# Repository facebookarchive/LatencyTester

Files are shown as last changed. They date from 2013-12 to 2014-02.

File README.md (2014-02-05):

Latency Tester
==============

Latency Tester

Firmware, Schematics, and Mechanicals for the Oculus Latency Tester.

https://www.oculusvr.com/order/latency-tester/

Firmware
--------

The Latency Tester firmware uses the CooCox CoIDE for development along with 
the gcc-arm-embedded toolchain.

The ST-Link/V2 is the cheapest way to load firmware onto a Latency Tester
board, though any SWD compatible programmer should work.  You can follow these steps
to set up a build environment and load firmware onto the board:

1. Install ST-Link drivers if you haven't: http://www.st.com/web/en/catalog/tools/PF258167
2. Install CoCenter: http://www.coocox.org/CooCox_CoIDE.htm
3. Through CoCenter, install CooCox and CoFlash
4. Install gcc-arm-embedded: https://launchpad.net/gcc-arm-embedded/+download
5. Set up gcc-arm-embedded in CooCox: http://www.coocox.org/CoIDE/Compiler_Settings.html
6. Clone our LatencyTester repository to C:\CooCox\CoIDE\workspace
7. Open the LatencyTester.coproj
8. Build
9. Plug the ST-Link into the board's 10 pin SWD header.
10. Plug in USB to power the board.
12. Download code to Flash 
13. Enjoy!

Note that the USB Product ID is set to 0x0101, which matches the production
version of the Latency Tester.  If you modify the firmware in a way that
changes the USB interface, please change the Product ID to 0x0100.

Mechanical
----------

The Mechanical folder contains STLs of a version of the Latency Tester housing
that is printable on low cost 3D printers as well as STEP files of the original
injection molded housing.

Schematics
----------

The Schematics folder contains an image of the schematic, as well as Eagle CAD files
of the schematic and board layout.

You can also order PCBs directly from OSH Park:

* Main PCB: http://oshpark.com/shared_projects/SHWtp0zm
* Sensor PCB: http://oshpark.com/shared_projects/nyOrdIp9

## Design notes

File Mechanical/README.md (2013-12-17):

License
=======
This work is licensed under a Creative Commons Attribution 4.0 International License.

http://creativecommons.org/licenses/by/4.0/

Assembly
--------
Print one latencytester-top without supports and one latencytester-bottom with supports. Latencytester-top can be printed with support material, but the logo on the front may not look as nice.

Glue the (already assembled) sensor board into the bottom of the latency tester bottom. Hot melt glue works well for this. Rotation is not critical, though you may have to twist the cable connecting the two boards a little to get the mounting holes to line up.

Press the main PCB into the top of the latency tester and screw it all together with three M2x6 machine screws. M2x5 up to M2x10 will also do.

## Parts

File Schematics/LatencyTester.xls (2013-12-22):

Qty | Value | Device | Package | Parts | Description | Part Number | Source
8 | 80 | R-US_R0402 | R0402 | R1 R2 R3 R4 R5 R6 R7 R8 | 0402 80 Ohm 5% Resistor
6 | 1.5K | R-US_R0402 | R0402 | R9 R12 R13 R14 R15 R16 | 0402 1.5K Ohm 5% Resistor
2 | 22 | R-US_R0402 | R0402 | R10 R11 | 0402 22 Ohm 5% Resistor
2 | 4.7K | R-US_R0402 | R0402 | R17 R18 | 0402 4.7K Ohm 5% Resistor
1 | 0.01uF | C-EUC0402 | C0402 | C3 | 0402 0.01uF X7R 10% Ceramic Capacitor
8 | 0.1uF | C-EUC0402 | C0402 | C4 C5 C6 C7 C9 C10 C11 C12 | 0402 0.1uF X7R 10% Ceramic Capacitor
2 | 1.0uF | C-EUC0402 | C0402 | C1 C8 | 0402 1.0uF X5R 10% Ceramic Capacitor
2 | 10uF | C-EUC0805 | C0805 | C2 C13 | 0805 10uF X5R 10% Ceramic Capacitor
1 | MMZ1005S601C | INDUCTOR-L0402 | C402 | L1 | 0402 Chip Ferrite Bead | MMZ1005S601C | Digikey
1 | 8.00MHz | RESONATOR-PQRV-C | PQRV | Z1 |  | PRQV8.00CR5010Y000 | Digikey
4 | BC807 | TRANSISTOR_BJT_PNP-SOT-323 | SOT-323 | Q1 Q2 Q3 Q4 | BJT | BC807-25W-7 | Mouser
1 | CON-USB-F-MINI-B-VERT | CON-USB-F-MINI-B-VERT | 651005136421 | USB1 | USB Female connector | 651005136421 | Digikey
1 | GO | SW_TACT_4P-ADTS2 | ADTS2 | SW1 |  | ADTS24NV | Digikey
1 | SWD-GRPB5 | SWD-GRPB5 | GRPB5 | J1 | DNP
1 | TCS3414FN | TCS3414FN | TCS3414FN | U1 | TAOS Digital Color Sensor | TCS3414FN | Digikey
1 | STM32F102C6 | IC_UC_STM32 | LQFP48 | U2 | STM32F102C6 | STM32F102C6T6A | Digikey
1 | TPS73533DRV | TPS735XXDRV | SON-6 | U3 | Texas Instruments 500mA | TPS73533DRVT | Digikey
1 | LTC-4624JR | LTC-4624JR | LTC-4624 | U4 | LITE-ON triple digit seven-segment display. | LTC-4624JR | Digikey
1 | TLC5916D | TLC5916D | SOIC-16 | U5 | TI 8-channel constant-current led sink drivers. | TLC5916IDR | Digikey

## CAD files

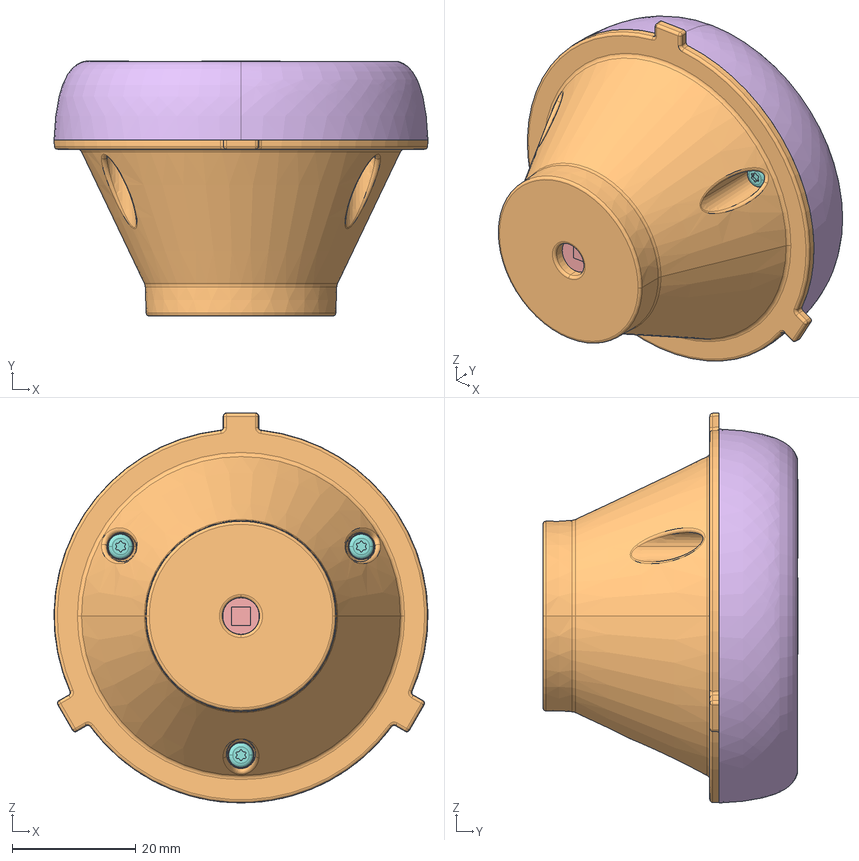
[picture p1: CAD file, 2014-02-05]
Mechanical/InjectionMoldingModels/Oculus latency tester assembly.stp
60.5 x 41.3 x 63.1 mm
OC00001
OCULUS_TOPPCB
OC00003
OCULUS_LOWERPCB
OC00002
OC00004
99397A192 x 3

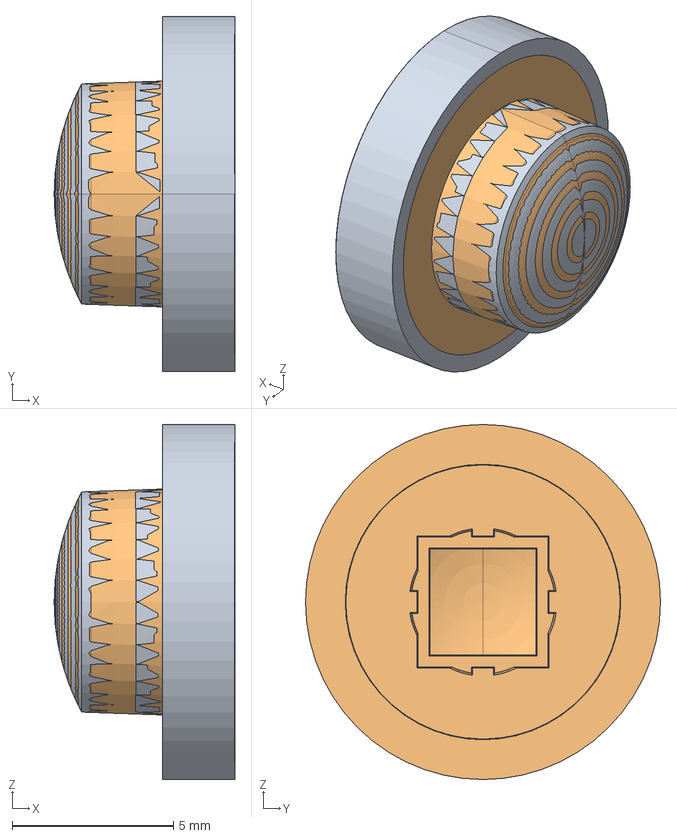
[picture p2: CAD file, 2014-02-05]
Mechanical/InjectionMoldingModels/Oculus latency tester button.stp
5.60 x 11.0 x 11.0 mm

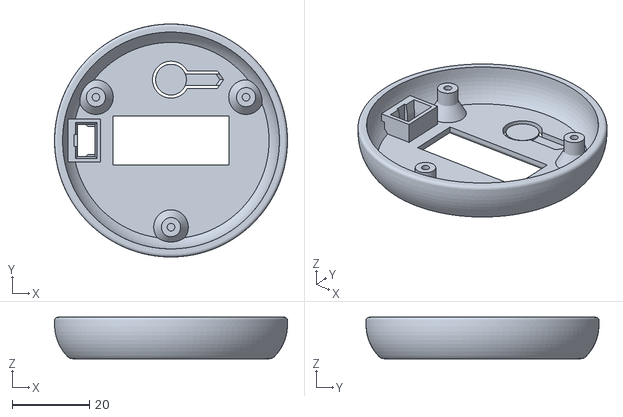
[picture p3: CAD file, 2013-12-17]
Mechanical/latencytester-top.stl
60.5 x 60.5 x 10.8

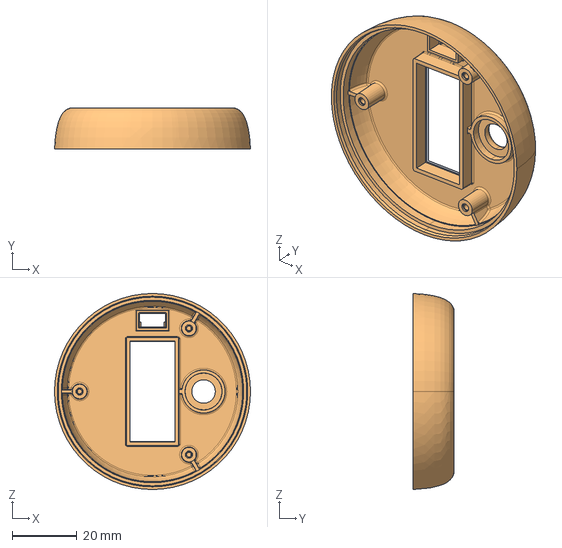
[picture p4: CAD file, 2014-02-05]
Mechanical/InjectionMoldingModels/Oculus latency tester upper housing.stp
60.5 x 12.8 x 60.5 mm

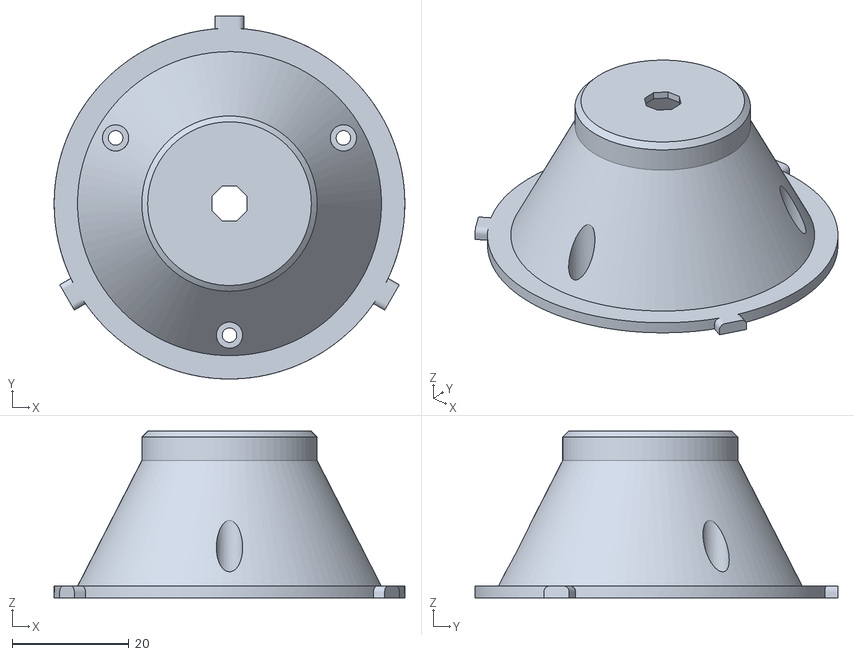
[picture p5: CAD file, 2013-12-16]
Mechanical/latencytester-bottom.stl
60.0 x 62.1 x 28.5

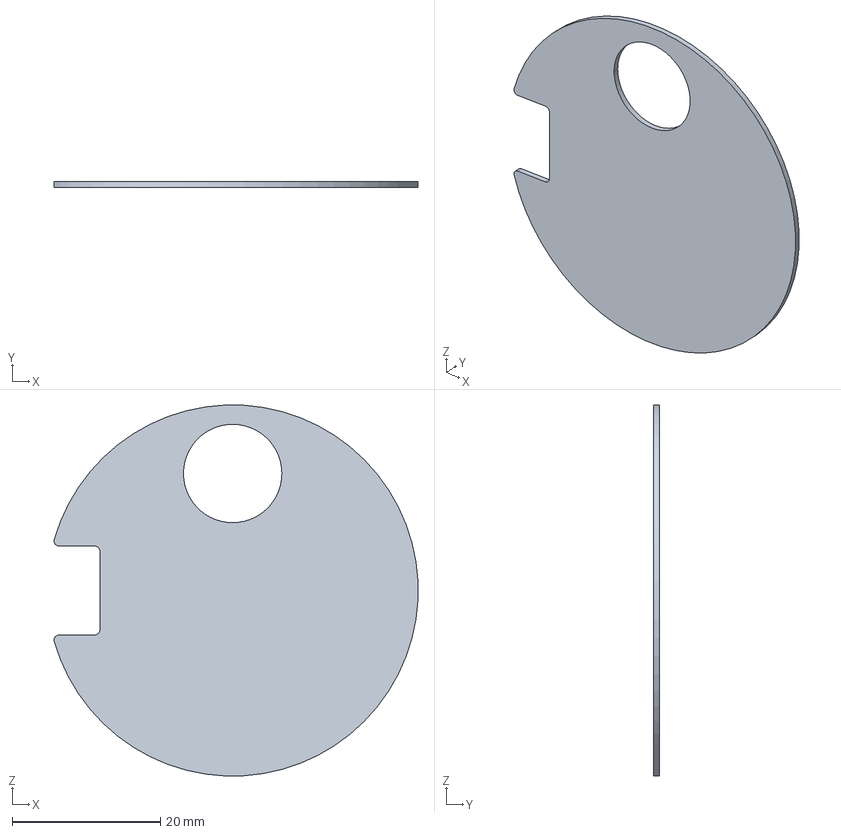
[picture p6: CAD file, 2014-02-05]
Mechanical/InjectionMoldingModels/Oculus latency tester label.stp
49.0 x 0.813 x 50.0 mm

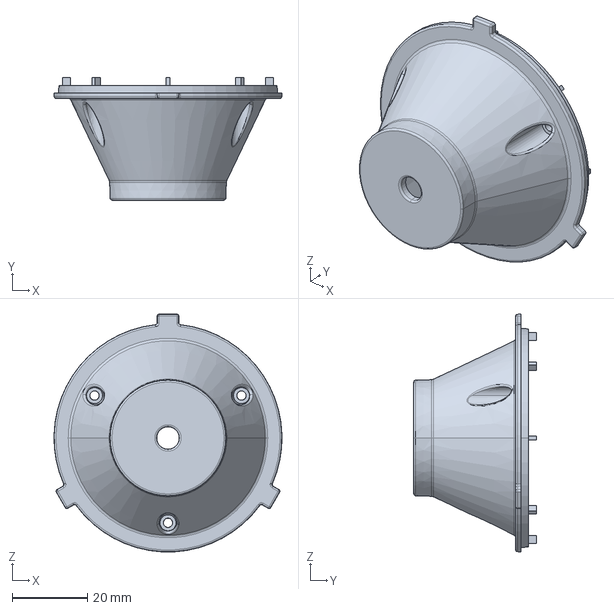
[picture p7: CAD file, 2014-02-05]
Mechanical/InjectionMoldingModels/Oculus latency tester lower housing.stp
60.5 x 32.5 x 63.1 mm

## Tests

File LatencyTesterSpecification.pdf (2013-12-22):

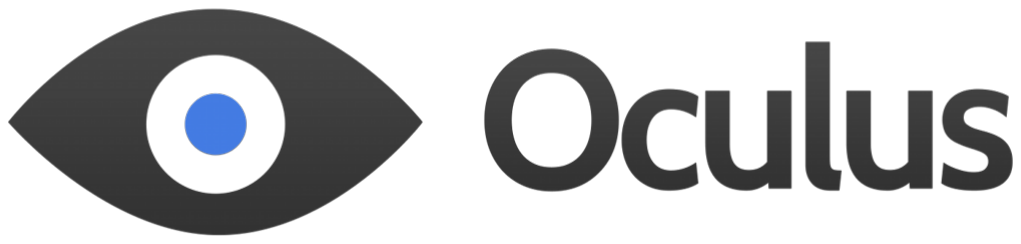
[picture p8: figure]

# Latency Tester Specification

### Nirav Patel

### Revision 0.4 3 March 2013

CONTENTS | CONTENTS

## Contents

1 Revision History | 3
2 Introduction | 4
3 Using the Latency Tester | 5
4 HID In Reports | 7
5 Feature Reports | 11
Latency Tester Specification | 2

1 REVISION HISTORY

## 1 Revision History

Revision | Date | Description
0.1 | 30-1-2013 | Preliminary specification.
0.2 | 7-2-2013 | Change button behavior, add bootloader.
0.3 | 23-2-2013 | Add usage instructions.
0.4 | 3-3-2013 | Rename reports and add Display report.
Latency Tester Specification | 3

2 INTRODUCTION

## 2 Introduction

Latency Tester is an HID class Full Speed USB device used to measure full system latency for the Oculus Rift. For more information about HID, see the Device Class Definition for Human Interface Devices¹
- Vendor ID: 0x2833
- Product ID: 0x0101
- Vendor String: Oculus VR, Inc.
- Product String: Latency Tester
- Serial String: Custom generated per device

1http://www.usb.org/developers/devclass_docs/HID1_11.pdf

Latency Tester Specification | 4

3 USING THE LATENCY TESTER

## 3 Using the Latency Tester

### 3.1 Timing the System

The simplest way to use the Latency Tester is to use it directly to time an event.

1. Flip the screen buffer from a color that is not the target color to the target color.
2. Send a StartTest report containing the target color.
3. Wait for the Latency Tester to return a ColorDetected packet, containing the time elapsed.

### 3.2 Emulating the Tracker

The usage of the Latency Tester can be tweaked slightly to more closely match the motion-to-photon behavior of the Tracker and Rift.

1. Make sure the screen is not at the target color.
2. Send a StartTest report containing the target color.
3. Wait for the Start packet from the Latency Tester.
4. Flip the screen buffer to the target color.
5. Wait for the Latency Tester to return a ColorDetected packet, containing the time elapsed.

### 3.3 Calibration

The Latency Tester comes calibrated for the Oculus Rift DK. It can also be re-calibrated to be used to test other displays. The calibration values are reset to the Oculus Rift DK values after resetting the device.

1. Set the screen to (0, 0, 0).
2. Send a Calibrate report with (0, 0, 0).
3. Set the screen to (255, 255, 255).
4. Send a Calibrate report with (255, 255, 255).
Latency Tester Specification | 5

3.4 Getting Sensor Samples | 3 USING THE LATENCY TESTER

### 3.4 Getting Sensor Samples

The Latency Tester can be configured to report a constant stream of color samples at 1000 Hz.

1. Send a Configuration report with the SendSamples bit set.
2. Read the Samples reports coming from the Tester.
Latency Tester Specification | 6

4 HID IN REPORTS

## 4 HID In Reports

The IN reports appear on Endpoint 1.

### 4.1 Samples

The 64 byte Sample report contains up to 20 RGB samples of light intensity data.

0 | 1 | 2 | 3 | 4 | 5 | 6 | 7 | 8 | 9 10 11 12 13 14 15 16 17 18 19 20 21 22 23 24 25 26 27 28 29 30 31
0 | ReportID = 1 | SampleCount | Timestamp
4 | Samples
❤❤❤❤❤❤❤❤❤❤❤❤❤❤❤❤❤❤❤❤❤❤❤❤❤❤❤❤❤❤❤❤❤❤❤ ❤❤❤❤

❤❤❤❤

❤❤❤❤

❤❤❤❤

❤❤❤❤

❤❤❤❤

❤❤❤❤

❤❤❤❤

❤❤❤

- ReportID (8 bits): The USB Report ID for this report is 1.
- SampleCount (8 bits): The number of RGB samples in the Samples field.
- Timestamp (16 bits): The timestamp of the first sample in the report. As the internal sampling rate is 1000 Hz, this unit is equivalent to milliseconds.
- Samples (60 bytes): Each sample is 3 bytes long and contains 8 bits each of red, green, and blue, which represents the luminosity values detected on the screen for each color at each sampling time.
Latency Tester Specification | 7

4.2 ColorDetected | 4 HID IN REPORTS

### 4.2 ColorDetected

The 13 byte ColorDetected report is fired when the Latency Tester detects that the screen has switched to within a threshold of the target value. The trigger is armed
by a StartTest feature report.
0 | 1 | 2 | 3 | 4 | 5 | 6 | 7 | 8 | 9 10 11 12 13 14 15 16 17 18 19 20 21 22 23 24 25 26 27 28 29 30 31
0 | ReportID = 2 | CommandID | Timestamp[0:7]
4 | Timestamp[8:15] | Elapsed | TriggerValue[0:7]
8 | TriggerValue[8:23] | TargetValue[0:15]
12 | TargetValue[16:23]
- ReportID (8 bits): The USB Report ID for this report is 2.
- CommandID (16 bits): An ID to identify related events, like a StartTest set, TestStarted report, and the resulting ColorDetected report.
- Timestamp (16 bits): The timestamp of the trigger fire. As the internal sampling rate is 1000 Hz, this unit is equivalent to milliseconds.
- Elapsed (16 bits): The time elapsed between the StartTest and the screen switching to within the threshold of the target value. The value is in milliseconds.
- TriggerValue (24 bits): The RGB sample that was within the threshold and triggered the firing of the report.
- TargetValue (24 bits): The RGB value that the display was set to.
Latency Tester Specification | 8

4.3 TestStarted | 4 HID IN REPORTS

### 4.3 TestStarted

The 8 byte TestStarted report is fired when a StartTest report is sent to it, indicating the start of the timer. A ColorDetected report will then be sent after the color change is detected.

0 | 1 | 2 | 3 | 4 | 5 | 6 | 7 | 8 | 9 10 11 12 13 14 15 16 17 18 19 20 21 22 23 24 25 26 27 28 29 30 31
0 | ReportID = 3 | CommandID | Timestamp[0:7]
4 | Timestamp[8:15] | TargetValue
- ReportID (8 bits): The USB Report ID for this report is 3.
- CommandID (16 bits): An ID to identify related events, like a StartTest report, TestStarted report, and the resulting ColorDetected report.
- Timestamp (16 bits): The timestamp of the test start. As the internal sampling rate is 1000 Hz, this unit is equivalent to milliseconds.
- TargetValue (24 bits): The RGB value that the display should be set to. This can be changed in the ButtonConfig feature report.
Latency Tester Specification | 9

4.4 Button | 4 HID IN REPORTS

### 4.4 Button

The 5 byte Button report is fired when the button on the Latency Tester is pressed.
It can be used by the application similarly to a keyboard button press to begin the StartTest, TestStarted, ColorDetected sequence.
0 | 1 | 2 | 3 | 4 | 5 | 6 | 7 | 8 | 9 10 11 12 13 14 15 16 17 18 19 20 21 22 23 24 25 26 27 28 29 30 31
0 | ReportID = 4 | CommandID | Timestamp[0:7]
4 | Timestamp[8:15]
- ReportID (8 bits): The USB Report ID for this report is 4.
- CommandID (16 bits): An ID to identify related events, like a StartTest, Test-Started report, and the resulting ColorDetected report.
- Timestamp (16 bits): The timestamp of the button press. As the internal sampling rate is 1000 Hz, this unit is equivalent to milliseconds.
Latency Tester Specification | 10

5 FEATURE REPORTS

## 5 Feature Reports

Feature Reports are read from and written to Endpoint 0, which is the Control Endpoint.

### 5.1 Configuration

The 5 byte Configuration report has a ReportID of 5. It contains a bitfield used to query or alter the operation of the Latency Tester.

0 | 1 | 2 | 3 | 4 | 5 | 6 | 7 | 8 | 9 10 11 12 13 14 15 16 17 18 19 20 21 22 23 24 25 26 27 28 29 30 31
0 | ReportID = 5 | a | Threshold[0:15]
4 | Threshold[16:23]
- ReportID (8 bits): The USB Report ID for this report is 5.
- (a) SendSamples (1 bit): Enables the Samples report. The default value is 0.
- Threshold (24 bits): The threshold for triggering a detected display change. For example, with a TargetValue of (255, 255, 255) a threshold set to (50, 50,
50) would result in a trigger at the first sample (205, 205, 205) or higher.
Latency Tester Specification | 11

5.2 Bootload | 5 FEATURE REPORTS

### 5.2 Bootload

The 4 byte Bootload report has a ReportID of 6. Setting the payload to non-zero reboots the device into a bootloading mode where new firmware can be loaded onto the Latency Tester over USB.

0 | 1 | 2 | 3 | 4 | 5 | 6 | 7 | 8 | 9 10 11 12 13 14 15 16 17 18 19 20 21 22 23 24 25 26 27 28 29 30 31
0 | ReportID = 6 | CommandID | Bootload
- ReportID (8 bits): The USB Report ID for this report is 6.
- CommandID (16 bits): Unused.
- Bootload (8 bits): Setting this to a non-zero value reboots the device into bootloader mode immediately.
Latency Tester Specification | 12

5.3 Calibrate | 5 FEATURE REPORTS

### 5.3 Calibrate

The 4 byte Calibrate report has a ReportID of 7. It is used to calibrate the color sensor in the Latency Tester to the display being tested. Set the display to a color, wait for the display to be completely switched, and then set the Calibrate report with that color. This should be repeated on any new display for the colors (255, 255, 255) and
(0, 0, 0).
0 | 1 | 2 | 3 | 4 | 5 | 6 | 7 | 8 | 9 10 11 12 13 14 15 16 17 18 19 20 21 22 23 24 25 26 27 28 29 30 31
0 | ReportID = 7 | Value
- ReportID (8 bits): The USB Report ID for this report is 7.
- Value (24 bit): The RGB value being calibrated to.
Latency Tester Specification | 13

5.4 StartTest | 5 FEATURE REPORTS

### 5.4 StartTest

The 6 byte StartTest report tells the Latency Tester to setup the change to the color specified in the report. The TestStarted report is sent back with the specified color when the timer starts.

0 | 1 | 2 | 3 | 4 | 5 | 6 | 7 | 8 | 9 10 11 12 13 14 15 16 17 18 19 20 21 22 23 24 25 26 27 28 29 30 31
0 | ReportID = 8 | CommandID | TargetValue[0:7]
4 | TargetValue[8:23]
- ReportID (8 bits): The USB Report ID for this report is 8.
- CommandID (16 bits): An ID to identify related events, like a StartTest, Test-Started report, and the resulting ColorDetected report.
- TargetValue (24 bits): The RGB value that the display is being set to.
Latency Tester Specification | 14

5.5 Display | 5 FEATURE REPORTS

### 5.5 Display

The 6 byte Display report configures and allows the setting of data on the 3.5 digit 7-segment display on the Latency Tester.

0 | 1 | 2 | 3 | 4 | 5 | 6 | 7 | 8 | 9 10 11 12 13 14 15 16 17 18 19 20 21 22 23 24 25 26 27 28 29 30 31
0 | ReportID = 9 | Mode | Value[0:15]
4 | Value[16:23]
- ReportID (8 bits): The USB Report ID for this report is 9.
- Mode (8 bits):
– 0: The default mode, where the Latency Tester automatically sets the value on the display when tests are run and completed. The Value field is ignored with this mode.
– 1: The display is set to the 32-bit unsigned integer in the Value field in milliseconds.
– 2: Raw access to the segments on the display using Value as a set of bitmasks. Byte 0 is Digit 1, byte 1 is the Colon digit, byte 2 is Digit 2, and byte 3 is Digit 3. See the LTC-4624 datasheet²
for bit to segment
mapping.
- Value (32 bits): The field depends on the Mode.

2http://optoelectronics.liteon.com/en-us/api/DwonloadFileHandler.ashx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 (http://optoelectronics.liteon.com/en-us/api/DwonloadFileHandler.ashx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)

Latency Tester Specification | 15

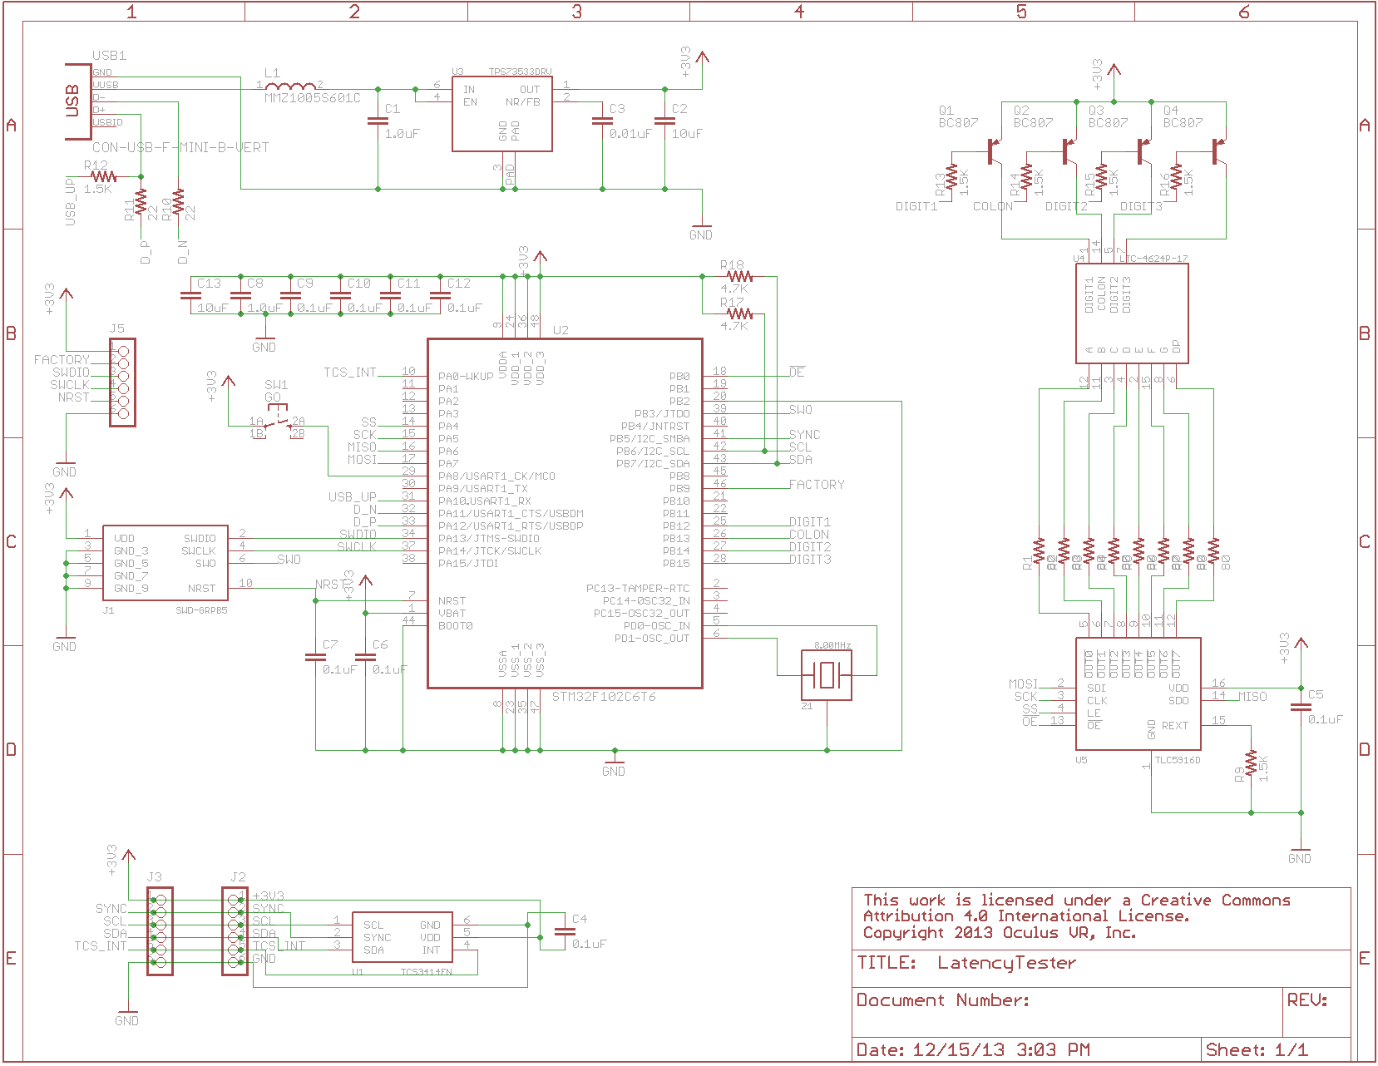
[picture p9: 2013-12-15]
Schematics/LatencyTester.png

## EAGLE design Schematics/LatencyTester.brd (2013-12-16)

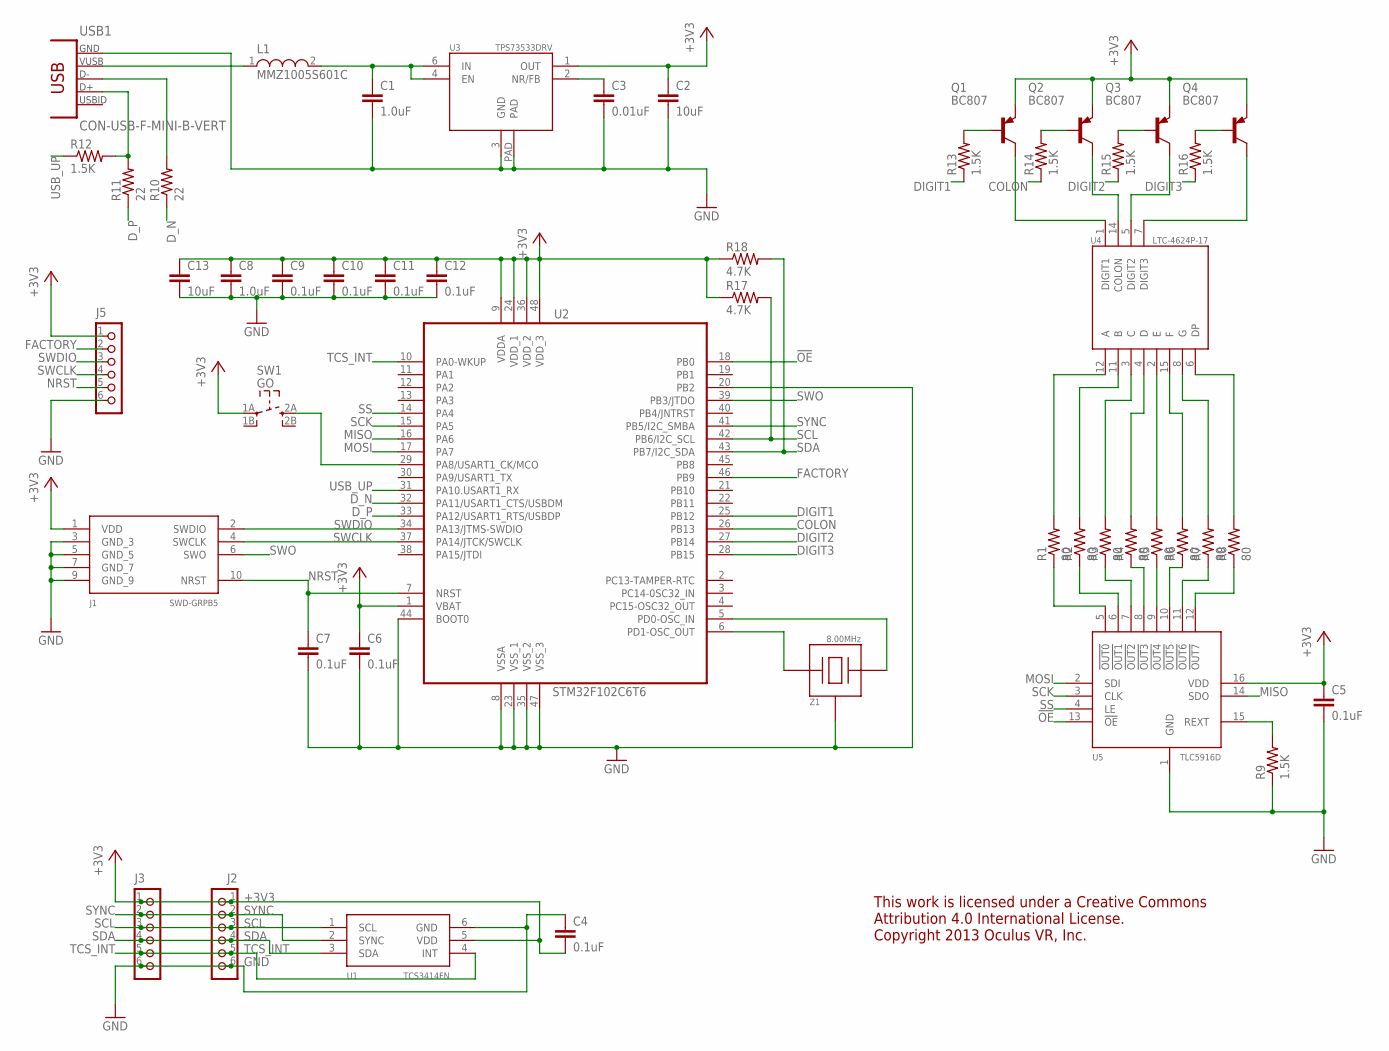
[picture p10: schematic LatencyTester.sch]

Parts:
C1, C8: 1.0uF; C0402
C2, C13: 10uF; C0805
C3: 0.01uF; C0402
C4, C5, C6, C7, C9, C10, C11, C12: 0.1uF; C0402
J1: SWD-GRPB5; GRPB5
J2, J3, J5: CON_HEADER_1X06-PTH; M1X6
L1: MMZ1005S601C; C402
Q1, Q2, Q3, Q4: BC807; SOT-323
R1, R2, R3, R4, R5, R6, R7, R8: 80; R0402
R9, R12, R13, R14, R15, R16: 1.5K; R0402
R10, R11: 22; R0402
R17, R18: 4.7K; R0402
SW1: GO; ADTS2
U1: TCS3414FN
U2: STM32F102C6T6; LQFP48
U3: TPS73533DRV; SON-6
U4: LTC-4624P-17; LTC-4624
U5: TLC5916D; SOIC-16
USB1: CON-USB-F-MINI-B-VERT; 651005136421
Z1: 8.00MHz; PQRV

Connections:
!OE: U2.18 (PB0), U5.13 (!OE)
+3V3: C2.1, C4.2, C5.1, C6.1, C8.1, C9.1, C10.1, C11.1, C12.1, C13.1, J1.1 (VDD), J2.1, J3.1, J5.1, Q1.2 (E), Q2.2 (E), Q3.2 (E), Q4.2 (E), R17.1, R18.1, SW1.1A (1), U1.5 (VDD), U2.1 (VBAT), U2.9 (VDDA), U2.24 (VDD_1), U2.36 (VDD_2), U2.48 (VDD_3), U3.1 (OUT), U5.16 (VDD)
COLON: R14.1, U2.26 (PB13)
D1_N: R10.2, USB1.2 (D-)
D1_P: R11.2, R12.2, USB1.3 (D+)
DIGIT1: R13.1, U2.25 (PB12)
DIGIT2: R15.1, U2.27 (PB14)
DIGIT3: R16.1, U2.28 (PB15)
D_N: R10.1, U2.32 (PA11/USART1_CTS/USBDM)
D_P: R11.1, U2.33 (PA12/USART1_RTS/USBDP)
FACTORY: J5.2, U2.46 (PB9)
GND: C1.2, C2.2, C3.2, C4.1, C5.2, C6.2, C7.2, C8.2, C9.2, C10.2, C11.2, C12.2, C13.2, J1.3 (GND_3), J1.5 (GND_5), J1.7 (GND_7), J1.9 (GND_9), J2.6, J3.6, J5.6, R9.1, U1.6 (GND), U2.8 (VSSA), U2.20 (PB2), U2.23 (VSS_1), U2.35 (VSS_2), U2.44 (BOOT0), U2.47 (VSS_3), U3.3 (GND), U3.PAD, U5.1 (GND), USB1.5 (GND), Z1.2 (GND)
MISO: U2.16 (PA6), U5.14 (SDO)
MOSI: U2.17 (PA7), U5.2 (SDI)
unnamed: R1.1, U5.5 (!OUT0)
unnamed: R2.1, U5.6 (!OUT1)
unnamed: R3.1, U5.7 (!OUT2)
unnamed: R4.1, U5.8 (!OUT3)
unnamed: R5.1, U5.9 (!OUT4)
unnamed: R6.1, U5.10 (!OUT5)
unnamed: R7.1, U5.11 (!OUT6)
unnamed: R8.1, U5.12 (!OUT7)
unnamed: R1.2, U4.12 (A)
unnamed: R2.2, U4.11 (B)
unnamed: R3.2, U4.3 (C)
unnamed: R4.2, U4.4 (D)
unnamed: R5.2, U4.2 (E)
unnamed: R6.2, U4.15 (F)
unnamed: R7.2, U4.8 (G)
unnamed: R8.2, U4.6 (DP)
unnamed: U2.6 (PD1-OSC_OUT), Z1.1 (IN)
unnamed: U2.5 (PD0-OSC_IN), Z1.3 (OUT)
unnamed: Q1.3 (C), U4.1 (DIGIT1)
unnamed: Q2.3 (C), U4.14 (COLON)
unnamed: Q3.3 (C), U4.5 (DIGIT2)
unnamed: Q4.3 (C), U4.7 (DIGIT3)
unnamed: SW1.2A (3), U2.29 (PA8/USART1_CK/MCO)
unnamed: C3.1, U3.2 (NR/FB)
unnamed: R9.2, U5.15 (REXT)
unnamed: Q1.1 (B), R13.2
unnamed: Q2.1 (B), R14.2
unnamed: Q3.1 (B), R15.2
unnamed: Q4.1 (B), R16.2
NRST: C7.1, J1.10 (NRST), J5.5, U2.7 (NRST)
SCK: U2.15 (PA5), U5.3 (CLK)
SCL: J2.3, J3.3, R17.2, U1.1 (SCL), U2.42 (PB6/I2C_SCL)
SDA: J2.4, J3.4, R18.2, U1.3 (SDA), U2.43 (PB7/I2C_SDA)
SS: U2.14 (PA4), U5.4 (LE)
SWCLK: J1.4 (SWCLK), J5.4, U2.37 (PA14/JTCK/SWCLK)
SWDIO: J1.2 (SWDIO), J5.3, U2.34 (PA13/JTMS-SWDIO)
SWO: J1.6 (SWO), U2.39 (PB3/JTDO)
SYNC: J2.2, J3.2, U1.2 (SYNC), U2.41 (PB5/I2C_SMBA)
TCS_INT: J2.5, J3.5, U1.4 (INT), U2.10 (PA0-WKUP)
USB_UP: R12.1, U2.31 (PA10.USART1_RX)
VUSB: L1.1, USB1.1 (VUSB)
VUSB_FILTERED: C1.1, L1.2, U3.4 (EN), U3.6 (IN)

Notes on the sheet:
This work is licensed under a Creative Commons Attribution 4.0 International License. Copyright 2013 Oculus VR, Inc.

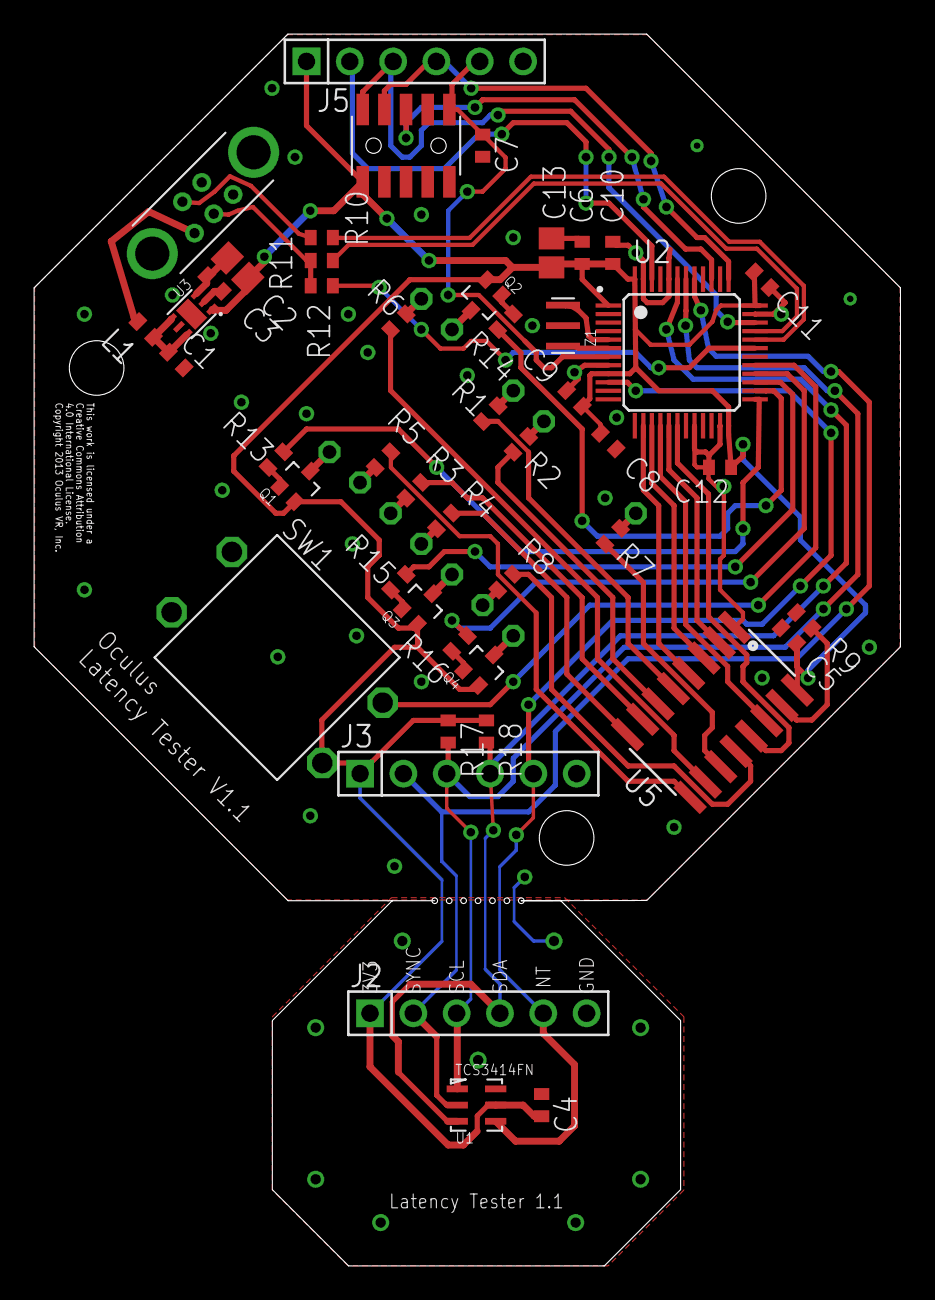
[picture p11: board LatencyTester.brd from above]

Board: 2 copper layers, 50.8 x 72.2 mm, 51 parts (0 on the bottom side), 56 nets.

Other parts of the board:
U$1, U$2, U$3: HOLE_3.2

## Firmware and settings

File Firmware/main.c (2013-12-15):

/*****************************************************************************

Filename    :   main.c
Content     :   Initialization and main loop for the Latency Tester
Created     :
Authors     :   Nirav Patel
Copyright   :   Copyright 2013 Oculus VR, Inc. All Rights reserved.

Licensed under the Apache License, Version 2.0 (the "License");
you may not use this file except in compliance with the License.
You may obtain a copy of the License at

http://www.apache.org/licenses/LICENSE-2.0

Unless required by applicable law or agreed to in writing, software
distributed under the License is distributed on an "AS IS" BASIS,
WITHOUT WARRANTIES OR CONDITIONS OF ANY KIND, either express or implied.
See the License for the specific language governing permissions and
limitations under the License.

*****************************************************************************/

#include "hw_config.h"
#include "usb_lib.h"
#include "usb_conf.h"
#include "usb_prop.h"
#include "usb_pwr.h"
#include "tick.h"
#include "sample_packet.h"
#include "feature_reports.h"
#include "trigger_packet.h"
#include "calibrate.h"
#include "tcs3414.h"
#include "segment.h"
#include <stdbool.h>
#include <stdlib.h>
#include <string.h>

static volatile bool ep1_ready = 1;

static feature_config_s config = {0};
static feature_dfu_s dfu = {0};
static feature_calibrate_s calibrate = {{0}};
static feature_trigger_s trigger = {0};
static feature_display_s display = {0};
static float sample_avg[3] = {0.0f};

uint8_t g_startup_failed;

#define DEBOUNCE (100)
#define TIMEOUT_OPTION (500)
#define AVG_ALPHA (0.4f)

#ifdef USE_TRACKER_V1
#define NUM_COLORS 2
#else
#define NUM_COLORS 3
#endif /* USE_TRACKER_V1 */

enum {
    MODE_IDLE,
    MODE_TRIGGER
};

enum {
    FACTORY_NONE,
    FACTORY_FULL,
    FACTORY_EMPTY,
    FACTORY_RED,
    FACTORY_GREEN,
    FACTORY_BLUE,
    FACTORY_DONE
};

static bool check_button_pressed(uint16_t timestamp)
{
    static bool button_value = 0;
    static uint16_t last_press = 0;

    bool ret = 0;
    bool new_value = GPIO_ReadInputDataBit(BUTTON_PORT, BUTTON_PIN);
    if (new_value && !button_value && ((uint16_t)(timestamp - last_press) > DEBOUNCE)) {
        ret = 1;
        last_press = timestamp;
    }

    button_value = new_value;
    return ret;
}

static void update_average(uint16_t *sample)
{
    for (uint8_t i = 0; i < NUM_COLORS; i++)
        sample_avg[i] = (sample[i]*AVG_ALPHA) + (sample_avg[i]*(1.0f-AVG_ALPHA));
}

static bool update_sample(uint16_t timestamp, uint8_t *sample, uint8_t *target, uint8_t *threshold)
{
    if (config.send_samples)
        sample_packet_update(timestamp, sample);

    // return 0 if any of the values are outside the threshold
    for (uint8_t i = 0; i < NUM_COLORS; i++) {
        if (abs(sample[i] - target[i]) > threshold[i]) {
            return 0;
        }
    }

    return 1;
}

static void update_factory(uint8_t factory_mode, uint8_t *sample)
{
    static const uint8_t full[] = {0xFF, 0xFF, 0xFF, 0xFF};
    static const uint8_t empty[] = {0, 0, 0, 0};

    switch (factory_mode) {
        case FACTORY_FULL:
            // Start by lighting all of the segments
            segment_set_raw(full);
            break;

        case FACTORY_EMPTY:
            // Then blank the display
            segment_set_raw(empty);
            break;

        case FACTORY_RED:
        case FACTORY_GREEN:
        case FACTORY_BLUE:
            // Then make sure each color in the sensor works
            segment_set_value(sample[factory_mode-FACTORY_RED]);
            break;
    }
}

int main(void)
{
    if (RCC_GetFlagStatus(RCC_FLAG_HSERDY) == RESET)
        g_startup_failed = 1;

    // Shut off JTAG and keep SWD on, needs to happen right after reset
    Configure_Debug();
    tick_init();

    // Initialize pins and interrupts
    Set_System();

    // Configure the USB hardware
    USB_Interrupts_Config();
    Set_USBClock();
    USB_Init();

#ifndef USE_AVAGO
    tcs_init();
#ifdef USE_7_SEG
    segment_init();
    if (g_startup_failed)
        segment_set_error();
    else
        segment_set_hello();
#endif /* USE_7_SEG */
#endif /* USE_AVAGO */

    uint32_t timestamp = tick_get();

    uint8_t sample[3] = {0};
    uint16_t raw[3] = {0};
    uint8_t sample_target[3] = {0};
    bool button_pressed = 0;
    bool got_trigger = 0;
    bool triggered = 0;
    bool got_report = 0;
    uint8_t mode = MODE_IDLE;
    uint8_t button_index = 0;
    uint32_t start_timestamp = 0;
    uint16_t command_id = 0;
    uint32_t trigger_timestamp = 0;
    uint32_t temp_timestamp = timestamp;

    // set the default values
    // TODO: for now, set the threshold to 128, 128, 255 since blue isn't connected
    config.threshold[0] = 128;
    config.threshold[1] = 128;
    config.threshold[2] = 255;

    feature_config_set(&config);

    // Check if we are in the programming/test jig
    uint8_t factory_mode = GPIO_ReadInputDataBit(FACTORY_PORT, FACTORY_PIN);

    while (1) {
        // Spin waiting for an event to happen
        do {
            temp_timestamp = tick_get();
            button_pressed |= check_button_pressed(temp_timestamp);
            got_report = feature_got_report();
        } while ((timestamp == temp_timestamp) &&
                 !button_pressed &&
                 !got_report);

        // Update feature reports if we got one
        if (got_report) {
            got_report = 0;
        }

        feature_config_get(&config);

        if (feature_calibrate_get(&calibrate)) {
            calibrate_update(sample_avg, calibrate.calibrate);
        }

        if (feature_dfu_get(&dfu)) {
            // TODO: Add HID bootloader support back to the Open Source release

            // Restart the device if we are told to
            if (dfu.use_dfu)
                Reset_Device();
        }

        if (feature_trigger_get(&trigger)) {
            got_trigger = 1;
            trigger_timestamp = timestamp;
        }

        if (feature_display_get(&display)) {
#ifdef USE_7_SEG
        	uint32_t value;

            // Update the display if we are in a mode where the PC sets it
            switch (display.mode) {
                case SEGMENT_MANUAL:
                	// Use memcpy to be safe about memory alignment
                	memcpy(&value, display.value, sizeof(uint32_t));
                    segment_set_value(value);
                    break;

                case SEGMENT_RAW:
                    segment_set_raw(display.value);
                    break;
            }
#endif /* USE_7_SEG */
        }

        // update the sample at every timestamp tick
        if (timestamp != temp_timestamp) {
            timestamp = temp_timestamp;
            // check if the color changed to the trigger value
#ifdef USE_AVAGO
            // TODO: connect blue
            raw[0] = ADC_GetConversionValue(ADC1);
            raw[1] = ADC_GetConversionValue(ADC2);
#else /* USE_AVAGO */
            tcs_end_measurement();
            tcs_start_measurement();
            tcs_read(raw);
#ifdef USE_7_SEG
            // only update the display if we are in auto mode and changes are happening
            if ((mode != MODE_IDLE) && (display.mode == SEGMENT_AUTO))
                segment_set_value(timestamp - start_timestamp);
            segment_update();
#endif /* USE_7_SEG */
#endif /* USE_AVAGO */

            update_average(raw);
            calibrate_apply(raw, sample);

            if (update_sample(timestamp, sample, sample_target, config.threshold) &&
                (mode != MODE_IDLE)) {
                triggered = 1;
            }
        }

        // Factory testing has several stages
        if (factory_mode) {
            if (button_pressed) {
                button_pressed = 0;
                factory_mode++;

                // Go into normal operation once testing is done
                if (factory_mode == FACTORY_DONE) {
                    factory_mode = FACTORY_NONE;
                    if (g_startup_failed)
                        segment_set_error();
                    else
                        segment_set_hello();
                }
            }

            update_factory(factory_mode, sample);

            continue;
        }

        if (triggered) {
            mode = MODE_IDLE;
            triggered = 0;
            // send the elapsed time if the trigger occurred
            uint32_t elapsed = timestamp - start_timestamp;
            trigger_packet(command_id, timestamp, elapsed > UINT16_MAX ? UINT16_MAX : elapsed, sample, sample_target);
            ep1_ready = 0;
        } else if (((mode == MODE_IDLE) || (timestamp - start_timestamp > TIMEOUT_OPTION)) && got_trigger) {
            // Only start the trigger if we aren't currently waiting for one
            mode = MODE_TRIGGER;
            got_trigger = 0;
            start_timestamp = trigger_timestamp;
            command_id = trigger.command_id;
            memcpy(sample_target, trigger.target, 3);
            trigger_start_packet(command_id, timestamp, sample_target);
            ep1_ready = 0;
        } else if (ep1_ready && button_pressed) {
            // increment the count used for the button each time
            button_index++;
            trigger_button_packet(button_index, timestamp);
            if ((display.mode == SEGMENT_AUTO))
                segment_set_waiting();
            button_pressed = 0;
            ep1_ready = 0;
        } else if (ep1_ready && config.send_samples) {
            // the normal sample packet has the lowest priority
            sample_packet_generate();
            sample_packet_send();
            ep1_ready = 0;
        }
    }
}

void EP1_IN_Callback(void)
{
    ep1_ready = 1;
}

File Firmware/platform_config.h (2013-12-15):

/*****************************************************************************

Filename    :   platform_config.h
Content     :   Pin definitions for the Latency Tester
Created     :
Authors     :   Nirav Patel
Copyright   :   Copyright 2013 Oculus VR, Inc. All Rights reserved.

Licensed under the Apache License, Version 2.0 (the "License");
you may not use this file except in compliance with the License.
You may obtain a copy of the License at

http://www.apache.org/licenses/LICENSE-2.0

Unless required by applicable law or agreed to in writing, software
distributed under the License is distributed on an "AS IS" BASIS,
WITHOUT WARRANTIES OR CONDITIONS OF ANY KIND, either express or implied.
See the License for the specific language governing permissions and
limitations under the License.

*****************************************************************************/

#ifndef _PLATFORM_CONFIG_H_
#define _PLATFORM_CONFIG_H_

#if defined(STM32L1XX_MD) || defined(STM32L1XX_HD)|| defined(STM32L1XX_MD_PLUS)
  #include "stm32l1xx.h"
#elif defined (STM32F10X_LD) || defined (STM32F10X_MD) || defined (STM32F10X_HD) || defined (STM32F10X_XL) || defined (STM32F10X_CL)
  #include "stm32f10x.h"
#endif

/* Define the STM32F10x hardware depending on the used evaluation board */
#if defined (USE_TRACKER_V1)

  #define USB_DISCONNECT                      GPIOA
  #define USB_DISCONNECT_PIN                  GPIO_Pin_2
  #define RCC_APB2Periph_GPIO_DISCONNECT      RCC_APB2Periph_GPIOA

#ifdef USE_AVAGO
  #define RED_PORT                            GPIOB
  #define RED_PIN                             GPIO_Pin_0
  #define RED_RCC                             RCC_APB2Periph_GPIOB
  #define RED_CHANNEL                         ADC_Channel_8
  #define GREEN_PORT                          GPIOB
  #define GREEN_PIN                           GPIO_Pin_1
  #define GREEN_RCC                           RCC_APB2Periph_GPIOB
  #define GREEN_CHANNEL                       ADC_Channel_9
  #define BLUE_PORT                           GPIOA
  #define BLUE_PIN                            GPIO_Pin_3
  #define BLUE_RCC                            RCC_APB2Periph_GPIOA
  #define BLUE_CHANNEL                        ADC_Channel_3
  #define BUTTON_PORT                         GPIOB
  #define BUTTON_PIN                          GPIO_Pin_10
  #define BUTTON_RCC                          RCC_APB2Periph_GPIOB
#else
  #define TCS_I2C                             I2C2
  #define TCS_I2C_RCC                         RCC_APB1Periph_I2C2
  #define TCS_SCL_PIN                         GPIO_Pin_10
  #define TCS_SDA_PIN                         GPIO_Pin_11
  #define TCS_SCL_SDA_PORT                    GPIOB
  #define TCS_SCL_SDA_RCC                     RCC_APB2Periph_GPIOB
  #define TCS_SYNC_PIN                        GPIO_Pin_5
  #define TCS_SYNC_PORT                       GPIOB
  #define TCS_SYNC_RCC                        RCC_APB2Periph_GPIOB
  #define BUTTON_PORT                         GPIOB
  #define BUTTON_PIN                          GPIO_Pin_0
  #define BUTTON_RCC                          RCC_APB2Periph_GPIOB
#endif /* USE_AVAGO */

#elif defined (USE_LATENCY_TESTER)

  #define USB_DISCONNECT                      GPIOA
  #define USB_DISCONNECT_PIN                  GPIO_Pin_10
  #define RCC_APB2Periph_GPIO_DISCONNECT      RCC_APB2Periph_GPIOA

  #define TCS_I2C                             I2C1
  #define TCS_I2C_RCC                         RCC_APB1Periph_I2C1
  #define TCS_SCL_PIN                         GPIO_Pin_6
  #define TCS_SDA_PIN                         GPIO_Pin_7
  #define TCS_SCL_SDA_PORT                    GPIOB
  #define TCS_SCL_SDA_RCC                     RCC_APB2Periph_GPIOB
  #define TCS_SYNC_PIN                        GPIO_Pin_5
  #define TCS_SYNC_PORT                       GPIOB
  #define TCS_SYNC_RCC                        RCC_APB2Periph_GPIOB

  #define BUTTON_PORT                         GPIOA
  #define BUTTON_PIN                          GPIO_Pin_8
  #define BUTTON_RCC                          RCC_APB2Periph_GPIOA

  #define FACTORY_PIN                         GPIO_Pin_9
  #define FACTORY_PORT                        GPIOB
  #define FACTORY_RCC                         RCC_APB2Periph_GPIOB
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

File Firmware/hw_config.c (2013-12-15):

/**
  ******************************************************************************
  * @file    hw_config.c
  * @author  MCD Application Team
  * @version V3.4.0
  * @date    29-June-2012
  * @brief   Hardware Configuration & Setup
  ******************************************************************************
  * @attention
  *
  * <h2><center>&copy; COPYRIGHT 2012 STMicroelectronics</center></h2>
  *
  * Licensed under MCD-ST Liberty SW License Agreement V2, (the "License");
  * You may not use this file except in compliance with the License.
  * You may obtain a copy of the License at:
  *
  *        http://www.st.com/software_license_agreement_liberty_v2
  *
  * Unless required by applicable law or agreed to in writing, software
  * distributed under the License is distributed on an "AS IS" BASIS,
  * WITHOUT WARRANTIES OR CONDITIONS OF ANY KIND, either express or implied.
  * See the License for the specific language governing permissions and
  * limitations under the License.
  *
  ******************************************************************************
  */


/* Includes ------------------------------------------------------------------*/

#include "hw_config.h"
#include "usb_lib.h"
#include "usb_desc.h"
#include "usb_pwr.h"
#include "stm32f10x_dbgmcu.h"
#include "stm32f10x_adc.h"
#include <stdbool.h>

/* Private typedef -----------------------------------------------------------*/
/* Private define ------------------------------------------------------------*/
/* Private macro -------------------------------------------------------------*/
/* Private variables ---------------------------------------------------------*/
ErrorStatus HSEStartUpStatus;
/* Extern variables ----------------------------------------------------------*/
/* Private function prototypes -----------------------------------------------*/
static void GPIO_Configuration(void);
static void ADC_Configuration(void);
/* Private functions ---------------------------------------------------------*/

void Configure_Debug(void)
{
  // Shut off JTAG since we only use SWD, so we can re-use the pins
  // This needs to happen shortly after reset
  RCC_APB2PeriphClockCmd(RCC_APB2Periph_AFIO, ENABLE);
  GPIO_PinRemapConfig(GPIO_Remap_SWJ_JTAGDisable, ENABLE);
  DBGMCU_Config(DBGMCU_SLEEP, ENABLE);
}

/*******************************************************************************
* Function Name  : Set_System.
* Description    : Configures Main system clocks & power.
* Input          : None.
* Output         : None.
* Return         : None.
*******************************************************************************/
void Set_System(void)
{
  /*!< At this stage the microcontroller clock setting is already configured,
       this is done through SystemInit() function which is called from startup
       file (startup_stm32f10x_xx.s) before to branch to application main.
       To reconfigure the default setting of SystemInit() function, refer to
       system_stm32f10x.c file
     */

  /* Enable the PWR clock */
  RCC_APB1PeriphClockCmd(RCC_APB1Periph_PWR, ENABLE);

  /* Configure the used GPIOs*/
  GPIO_Configuration();

  ADC_Configuration();
}

/*******************************************************************************
* Function Name  : Set_USBClock.
* Description    : Configures USB Clock input (48MHz).
* Input          : None.
* Output         : None.
* Return         : None.
*******************************************************************************/
void Set_USBClock(void)
{
#if defined(STM32L1XX_MD) || defined(STM32L1XX_HD)|| defined(STM32L1XX_MD_PLUS)
  /* Enable USB clock */
  RCC_APB1PeriphClockCmd(RCC_APB1Periph_USB, ENABLE);

#elif defined(STM32F10X_CL)
  /* Select USBCLK source */
  RCC_OTGFSCLKConfig(RCC_OTGFSCLKSource_PLLVCO_Div3);

  /* Enable the USB clock */
  RCC_AHBPeriphClockCmd(RCC_AHBPeriph_OTG_FS, ENABLE) ;

#else
#ifdef USE_F102
  RCC_USBCLKConfig(RCC_USBCLKSource_PLLCLK_Div1);
#else /* USE_F102 */
  RCC_USBCLKConfig(RCC_USBCLKSource_PLLCLK_1Div5);
#endif /* USE_F102 */

  /* Enable the USB clock */
  RCC_APB1PeriphClockCmd(RCC_APB1Periph_USB, ENABLE);
#endif /* STM32F10X_CL */
}

void Enter_Stop(void)
{
    // Going into stop mode works, but the USB wakeup interrupt never fires.
    // Instead, just shut off the external resonator and PLL and go to
    // 8 MHz internal RC.  Gets us down to ~1.7 mA.
//    DBGMCU_Config(DBGMCU_SLEEP | DBGMCU_STANDBY | DBGMCU_STOP, ENABLE);
//    PWR_EnterSTOPMode(PWR_Regulator_ON, PWR_STOPEntry_WFI);
//
//    RCC_HSICmd(ENABLE);
//
//    /* Wait till HSI is ready */
//    while (RCC_GetFlagStatus(RCC_FLAG_HSIRDY) == RESET) {}
//
//    /* Select HSI as system clock source */
//    RCC_SYSCLKConfig(RCC_SYSCLKSource_HSI);
//
//    /* Disable PLL1 */
//    RCC_PLLCmd(DISABLE);
//
//    /* Disable HSE */
//    RCC_HSEConfig(RCC_HSE_OFF);
//
//    // Shut off core clocks
//    __WFI();
}
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

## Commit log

2013-12-15 Initial untested port of LatencyTester firmware
    Porting to use CooCox and gcc-arm-embedded.
    Also add Apache license headers to our files.
2013-12-15 Latency Tester Schematic
2013-12-16 Added latency tester STLs
    [latencytester-bottom.stl, latencytester-button.stl, latencytester-spacer.stl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]
2013-12-16 Top fits PCB better, now buttonless design
    [latencytester-bottom.stl, latencytester-button.stl, latencytester-top.stl]
2013-12-16 Add Eagle files of the board
    [LatencyTester.brd, LatencyTester.sch]
2013-12-17 No more PCB spacer, minor tweaks to top
    [latencytester-spacer.stl, latencytester-top.stl]
2013-12-22 Add interface specification and BOM
    [LatencyTester.xls]
2014-02-05 Add OSH Park PCB urls
2014-02-05 STEP files for the injection molded housing
    [Oculus latency tester assembly.stp, Oculus latency tester button.stp, Oculus latency tester label.stp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]
2014-02-05 Mention the injection molded housing model
